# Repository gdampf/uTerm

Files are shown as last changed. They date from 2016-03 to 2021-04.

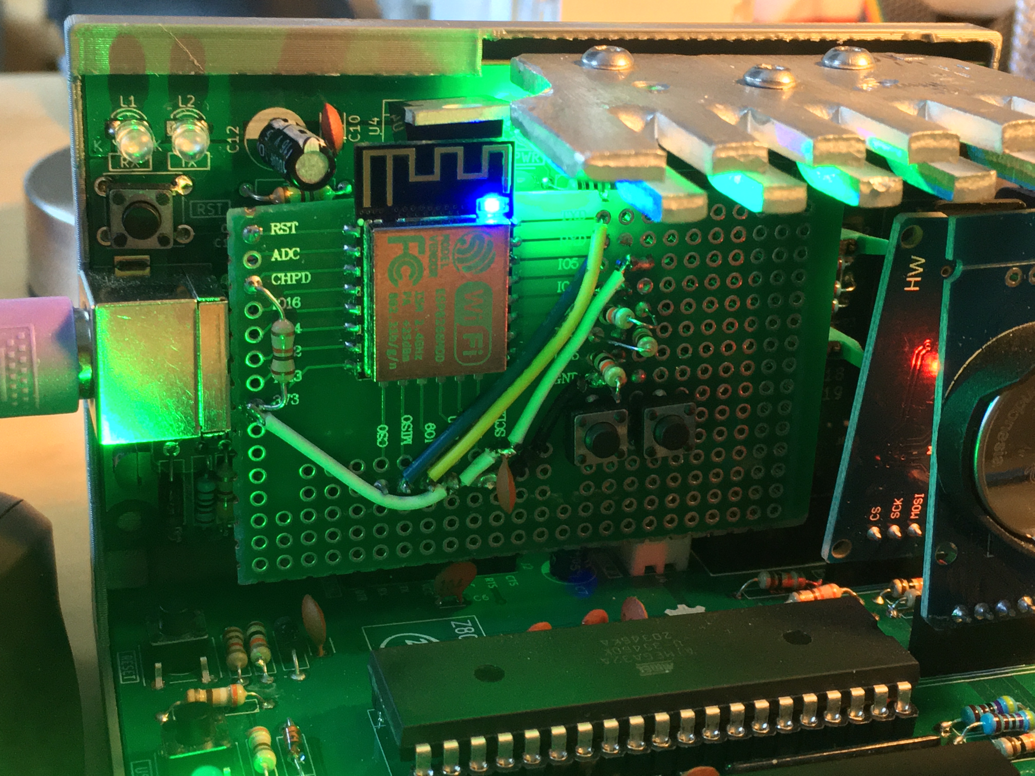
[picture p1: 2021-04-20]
21-04-20 07-18-13 2878.jpg

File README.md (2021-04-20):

## uTerm

uTerm (micro-Term) is a VT100-like terminal for the Z80-MBC2 (https://hackaday.io/project/159973). It has a VGA out and PS/2 keyboard connector, a power supply for the Z80-MBC2 and a "transparent" serial-USB port.

This fork of https://github.com/SuperFabius/uTerm was originally made for supporting German Keyboard-Layout.
Then, I recognized, that some kind of keyboards with PS/2 doesn't react at the given firmware. They are just sending out 0xAA all the time and no key codes. By comparing the signals to a system, where they are working fine, I found that they need a reset (0xff), to work propperly.
This fork solve therefore three things:

1. the state machine for the keyboard has been changed to support this kind of keyboards, which are waiting for reset.
2. the right alt key is now used as a separate modifier to support the ALTGR-Codes on many non US-Keyboard-Layouts.
3. the keys are changed corresponding to German Layout

To compile this code, I used Keil µVision5 under Windows X!

I further added the code for using an ESP8266 for using telnet via WiFi.

Here comes the original Text:

These are the sources modified for the uTerm forked from the Madis Kaal 
repository (forked from the original repository of K. C. Lee: 
https://github.com/FPGA-Computer/STM32F030F4-VGA. Original project 
page: https://hw-by-design.blogspot.com/2018/07/low-cost-vga-terminal-module-project.html)

uTerm "project" page: https://hackaday.io/project/165325

NOTE: I've updated here only the changed source files, so you must recompile all to get the new executable.

Supported uTerm boards:

- A071218-R250119
- A071218-R290319

Supported uTerm-S boards:

- A200419

------------------------------------------------------------------------------

**UPDATE (11/2019):** Solved a bug (by gkaufman) using the right CTRL key in some situations (i.e. CTRL-L)

------------------------------------------------------------------------------

In the following the original text. 

------------------------------------------------------------------------------
------------------------------------------------------------------------------

VT100 emulation, font editor, 16-line font, and support for inverse fonts
added by Madis Kaal <mast@nomad.ee> http://www.nomad.ee

The individual license(s) are in each directories.

Directories:
------------------------------------------------------------------------------
font conv/ 
- source code + Windows console executable for a font conversion program.
It imports GLCD font Creator file and converter it to a C font table
of the comverted scan line bitmaps that is to be used with the VGA library.

- The converter is compiled using Pelles C
http://www.pellesc.de/index.php?page=start&lang=en

- "GLCD Font Creator" MikroElektronika
http://www.mikroe.com/glcd-font-creator/

Code in this directory is licensed under "Simplified BSD License"

-------------------------------------------------------------------------------
STM32F030F4/Hardware/LT Spice Simulation
files in this directory is licensed under "Simplified BSD License"

-------------------------------------------------------------------------------
STM32F030F4/Hardware/Sketchup 3D Model
Creative Commons 4.0 Attribution-NonCommercial-NoDerivs International
http://creativecommons.org/licenses/by-nc-nd/4.0/

This is to prevent someone photoshopping this as their own project for crowd-funding 
scams. You are free to generate your own model using Eagleup from your new layout.

-------------------------------------------------------------------------------
STM32F030F4/Hardware/
Schematic/Layout is distributed with Creative Commons 4.0 Attribution-NonCommercial
http://creativecommons.org/licenses/by-nc/4.0/

If you want to sell this and want a different licensing term, please contact me.

-------------------------------------------------------------------------------
STM32F030F4/Firmware/

Source code distributed under GPLV3, with exception of fontedit.py that is
distributed under BSD license.

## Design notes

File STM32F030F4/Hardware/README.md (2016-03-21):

ChibiTerm
---------
This is the repository for the Low Cost VGA Terminal Module PCB.

Licensing:
Schematic/Layout is distributed with Creative Commons 4.0 Attribution-NonCommercial

3D modelling: Creative Commons 4.0 Attribution-NonCommercial-NoDerivs International
This is to prevent someone photoshopping this as their own project for crowd-funding scams. You are allowed to generate your own model using Eagleup from your new layout.

Creative Commons 4.0 Attribution-NonCommercial:
See http://creativecommons.org/licenses/by-nc/4.0/

Creative Commons 4.0 Attribution-NonCommercial-NoDerivatives International
See http://creativecommons.org/licenses/by-nc-nd/4.0/

If you want to sell this and want a different licensing term, please contact me.

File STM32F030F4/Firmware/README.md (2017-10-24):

This is a STM32F030F4 VGA library + project for HaD 2016 Contest Entry.

Project webpage: 
https://hackaday.io/project/9992

-------------------------------------------------------------------------------
STM32F030F4/Firmware/

Source code distributed under GPLV3 except the font file and startup_stm32f030.s

startup_stm32f030.s:
http://www.st.com/software_license_agreement_liberty_v2

fontedit.py by Madis Kaal is distributed with BSD license
See http://www.nomad.ee

VGA font "Less Perfect DOS VGA" is converted from:
http://laemeur.sdf.org/fonts/
"More Perfect DOS VGA and Less Perfect DOS VGA are both free for all use, 
commercial and non-commercial. IBM designed the glyphs and Zeh Fernando did 
most of the work converting them to TrueType, so I don't claim ownership of 
anything."

VGA font "Term_hex.fon" is converted from:
https://sourceforge.net/projects/realterm/files/z_Special%20Fonts/Hex%20Fonts/
It has a BSD license.

Matrix Clock Demo:
This is a Matrix style Clock running in VGA 640x480 Text mode 
using the schematic in the hardware section.

Source code is a bit rough and out of date with the development branch as this 
is a quick demo for the VGA Text code in its early stage.

ChibiTerm:
This is the source code directory for ChibiTerm terminal program.  This is the
main development branch.

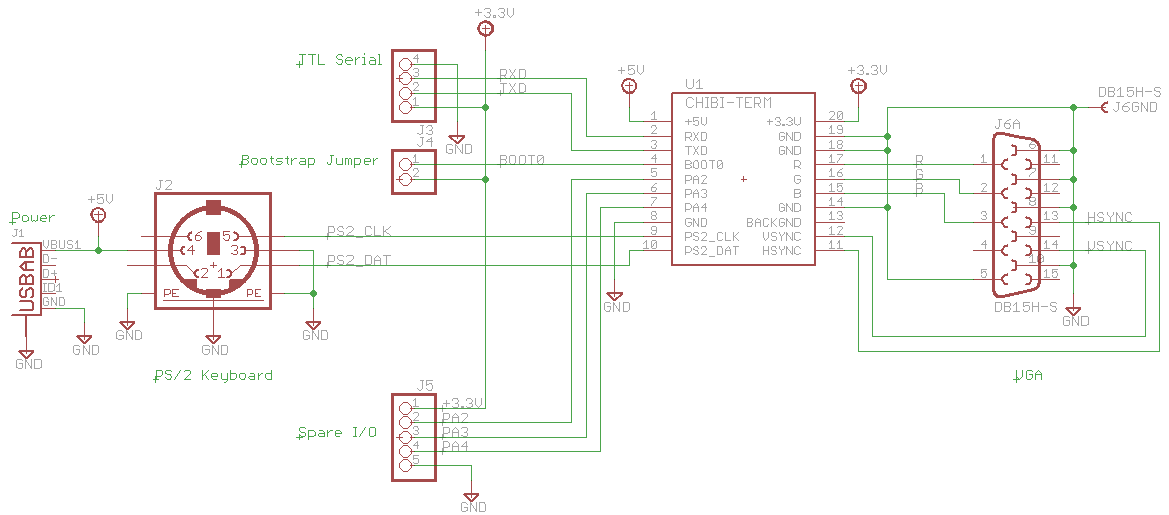
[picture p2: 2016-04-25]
STM32F030F4/Hardware/Module Connections.png

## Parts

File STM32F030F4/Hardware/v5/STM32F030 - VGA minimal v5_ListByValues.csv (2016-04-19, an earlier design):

Qty | Value | Part Num | Package | Parts
1 |  | 0.1 IN HEADER 1X4 | 1X04 | J2
2 |  | 0.1 IN HEADER 1X10 | 1X10 | J1, J3
2 | 0.1uF | 0.1UF, 0603 | CAPC1608X92N | C4, C8
1 | 1uF | 1UF, 0603 | CAPC1608X92N | C9
1 | 1uF | 1UF, 0805 | CAPC2012X145AN | C3
1 | 2K | 2K, 0603 | RESC1608X55N | R4
3 | 4K7 | 4K7, 0603 | RESC1608X55N | R1, R3, R5
2 | 5V1 Zener | BZT52C5V1 | SOD-123 | D1, D2
1 | 10uF | 10UF/10V X5R 0805 | CAPC2012X145AN | C1
3 | 22pF | 22PF, 0603 | CAPC1608X92N | C5, C6, C10
1 | 25MHz | 25MHZ FUND. HC49 | SM49 | X1
2 | 220R | CAT16-221J4 | CAT16 | RN1, RN2
3 | 475R | 475R, 0603 | RESC1608X55N | R2, R6, R7
1 | 3904 | MMBT3904 | SOT95P280X135-3N | Q1
1 | BAT54 | BAT54 | SOT95P280X135-3N | D3
1 | CC-BY-NC | LICENSE | CC-BY-NC-75 | LICENSE
1 | MCP1700/TT | MCP1700T-3302E/TT | SOT95P280X135-3N | U1
1 | STM32F030F4P6 | STM32F030F4P6 | TSSOP20 | U2

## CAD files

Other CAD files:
win32/output/fontconv.obj
STM32F030F4/Hardware/Sketchup 3D Model/Rev. 5.skp

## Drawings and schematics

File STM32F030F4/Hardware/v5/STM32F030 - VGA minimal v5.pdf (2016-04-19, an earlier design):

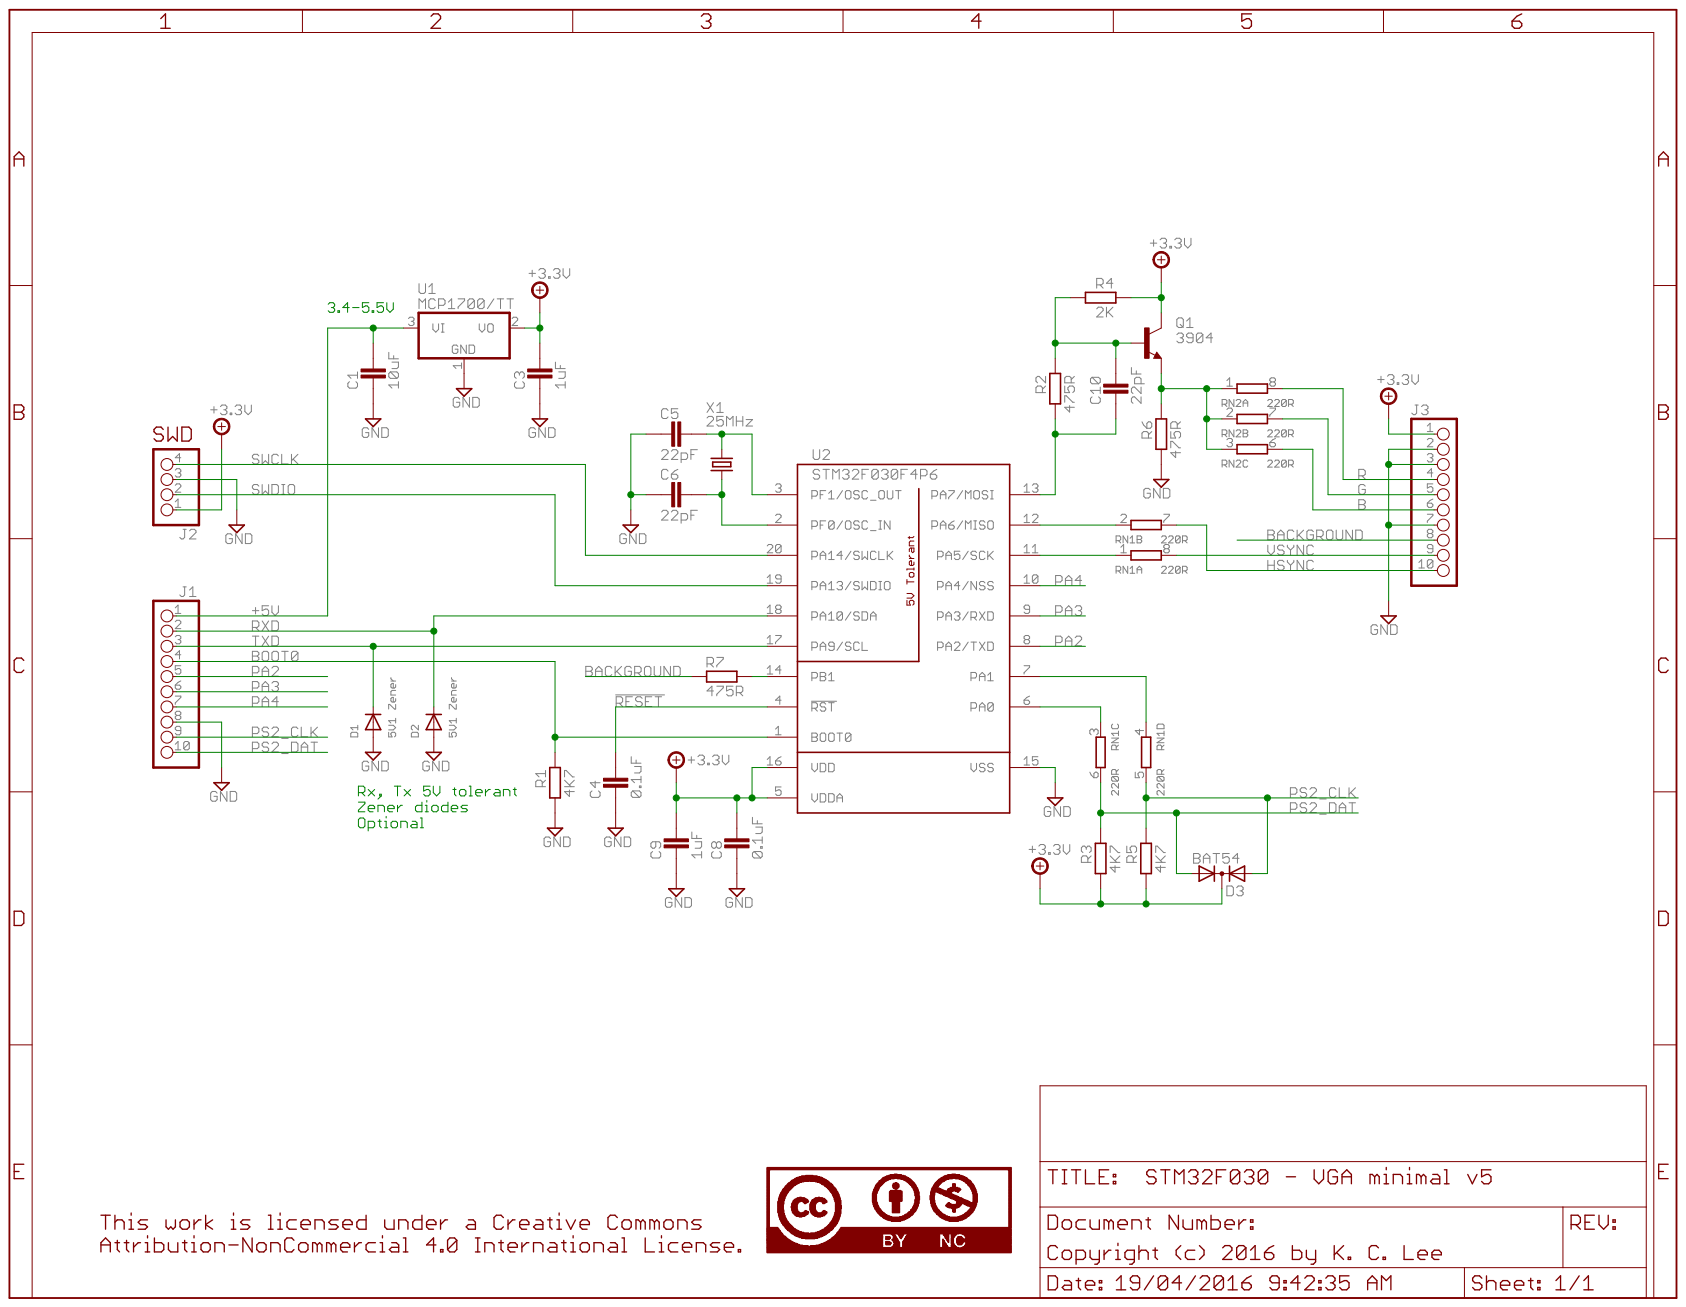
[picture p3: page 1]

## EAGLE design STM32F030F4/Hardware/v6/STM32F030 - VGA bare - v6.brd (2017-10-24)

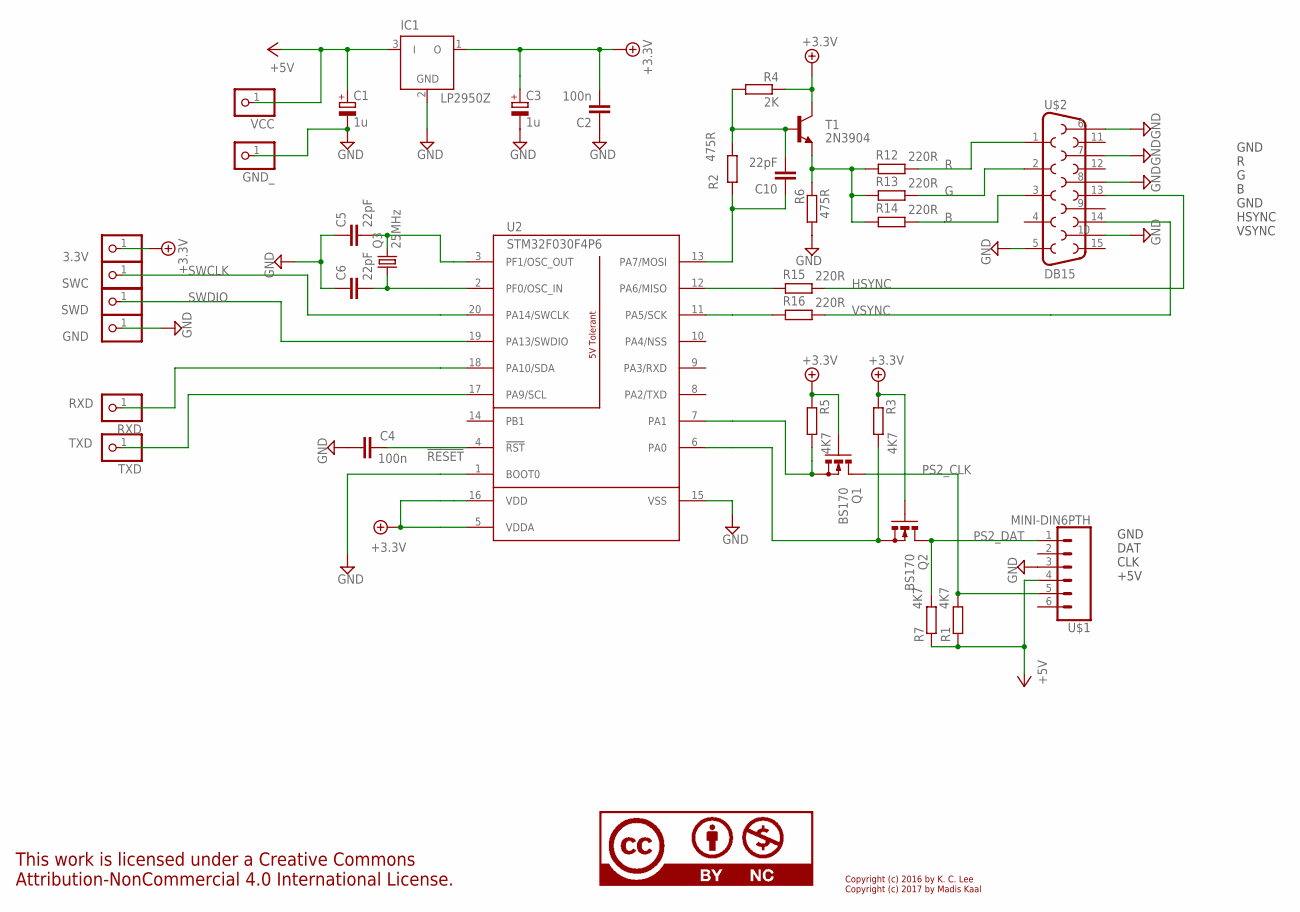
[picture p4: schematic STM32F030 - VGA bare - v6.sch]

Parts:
3.3V: PINHD-1X1; 1X01
C1, C3: 1u; E2,5-5
C2, C4: 100n; C025-025X050; PARTNO 0.1UF, 0603
C5, C6, C10: 22pF; C025-025X050; PARTNO 22PF, 0603
GND: PINHD-1X1; 1X01
GND_: PINHD-1X1; 1X01
IC1: LP2950Z; TO92
LICENSE: CC-BY-NC; CC-BY-NC-75; PARTNO LICENSE
Q1, Q2: BS170; SOT54E
Q3: 25MHz; HC49U-V
R1, R3, R5, R7: 4K7; 0204/7; PARTNO 4K7, 0603
R2, R6: 475R; 0204/7; PARTNO 475R, 0603
R4: 2K; 0204/7; PARTNO 2K, 0603
R12, R13, R14, R15, R16: 220R; 0204/7
RXD: PINHD-1X1; 1X01
SWC: PINHD-1X1; 1X01
SWD: PINHD-1X1; 1X01
T1: 2N3904; TO92
TXD: PINHD-1X1; 1X01
U2: STM32F030F4P6; TSSOP20; PARTNO STM32F030F4P6
U$1: MINI-DIN6PTH; MINI-DIN6
U$2: DB15
VCC: PINHD-1X1; 1X01

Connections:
!RESET: C4.1, U2.4 (!RST)
+3.3V: 3.3V.1, C2.2, C3.+, IC1.1 (O), Q1.G, Q2.G, R3.2, R4.1, R5.2, T1.1 (C), U2.5 (VDDA), U2.16 (VDD)
+5V: C1.+, IC1.3 (I), R1.2, R7.2, U$1.4, VCC.1
B: R14.1, U$2.3
G: R13.1, U$2.2
GND: C1.-, C2.1, C3.-, C4.2, C5.1, C6.1, GND.1, GND_.1, IC1.2 (GND), R6.2, U2.1 (BOOT0), U2.15 (VSS), U$1.3, U$2.5, U$2.6, U$2.7, U$2.8, U$2.10
HSYNC: R15.1, U$2.13
unnamed: R6.1, R12.2, R13.2, R14.2, T1.3 (E)
unnamed: R15.2, U2.12 (PA6/MISO)
unnamed: Q1.S, R5.1, U2.7 (PA1)
unnamed: C5.2, Q3.2, U2.3 (PF1/OSC_OUT)
unnamed: C6.2, Q3.1, U2.2 (PF0/OSC_IN)
unnamed: Q2.S, R3.1, U2.6 (PA0)
unnamed: R16.2, U2.11 (PA5/SCK)
unnamed: C10.2, R2.1, R4.2, T1.2 (B)
unnamed: C10.1, R2.2, U2.13 (PA7/MOSI)
PS2_CLK: Q1.D, R1.1, U$1.5
PS2_DAT: Q2.D, R7.1, U$1.1
R: R12.1, U$2.1
RXD: RXD.1, U2.18 (PA10/SDA)
SWCLK: SWC.1, U2.20 (PA14/SWCLK)
SWDIO: SWD.1, U2.19 (PA13/SWDIO)
TXD: TXD.1, U2.17 (PA9/SCL)
VSYNC: R16.1, U$2.14

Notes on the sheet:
GND R G B GND HSYNC VSYNC
GND DAT CLK +5V
Copyright (c) 2016 by K. C. Lee Copyright (c) 2017 by Madis Kaal

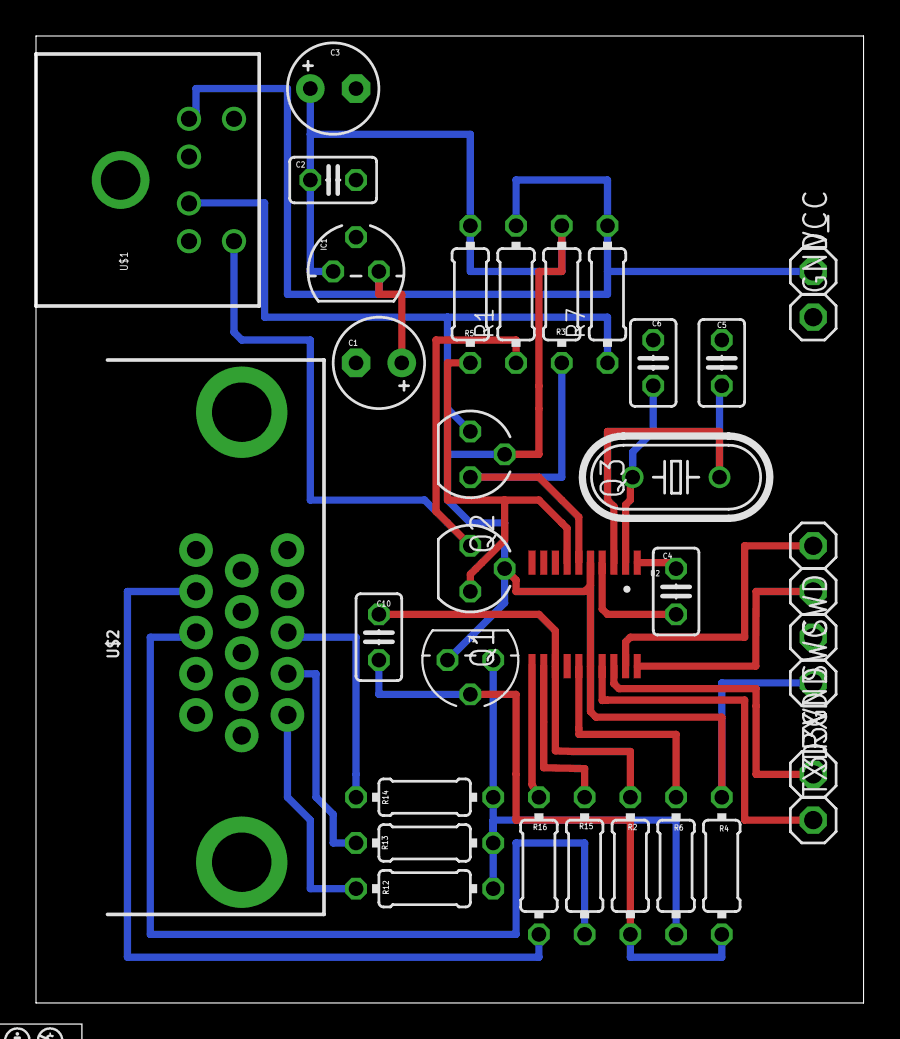
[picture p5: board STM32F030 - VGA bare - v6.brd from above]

Board: 2 copper layers, 46.0 x 53.7 mm, 36 parts (0 on the bottom side), 24 nets.

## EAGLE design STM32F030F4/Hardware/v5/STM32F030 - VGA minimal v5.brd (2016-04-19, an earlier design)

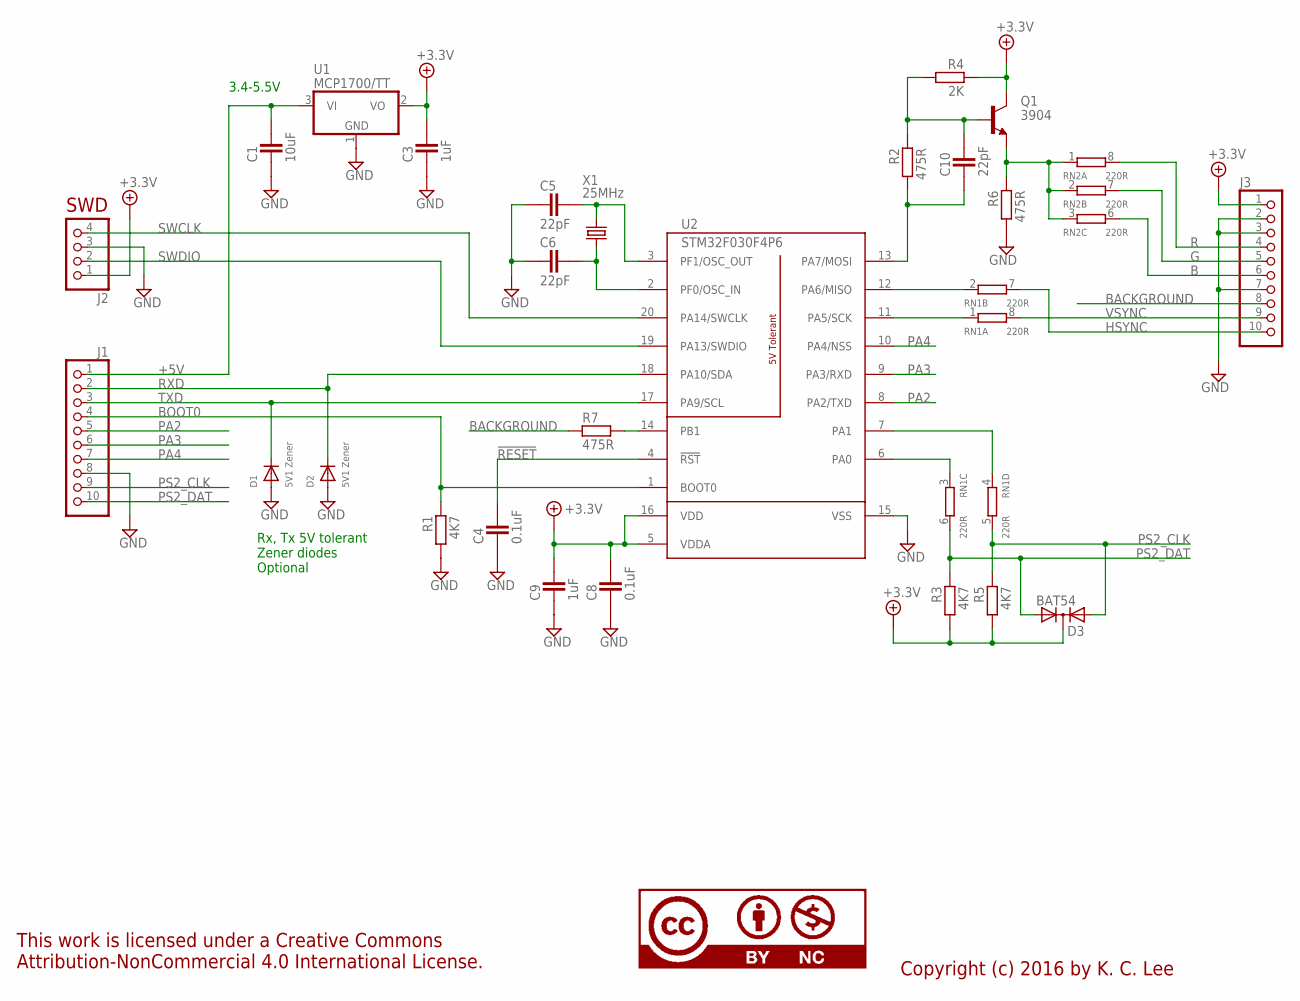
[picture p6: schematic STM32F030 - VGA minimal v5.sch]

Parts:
C1: 10uF; CAPC2012X145AN; PARTNO 10UF/10V X5R 0805
C3: 1uF; CAPC2012X145AN; PARTNO 1UF, 0805
C4, C8: 0.1uF; CAPC1608X92N; PARTNO 0.1UF, 0603
C5, C6, C10: 22pF; CAPC1608X92N; PARTNO 22PF, 0603
C9: 1uF; CAPC1608X92N; PARTNO 1UF, 0603
D1, D2: 5V1 Zener; SOD-123; PARTNO BZT52C5V1
D3: BAT54; SOT95P280X135-3N; PARTNO BAT54
J1, J3: PINHD-1X10; 1X10; PARTNO 0.1 IN HEADER 1X10
J2: PINHD-1X4_2.54; 1X04; PARTNO 0.1 IN HEADER 1X4
LICENSE: CC-BY-NC; CC-BY-NC-75; PARTNO LICENSE
Q1: 3904; SOT95P280X135-3N; PARTNO MMBT3904
R1, R3, R5: 4K7; RESC1608X55N; PARTNO 4K7, 0603
R2, R6, R7: 475R; RESC1608X55N; PARTNO 475R, 0603
R4: 2K; RESC1608X55N; PARTNO 2K, 0603
RN1, RN2: 220R; CAT16; PARTNO CAT16-221J4
U1: MCP1700/TT; SOT95P280X135-3N; PARTNO MCP1700T-3302E/TT
U2: STM32F030F4P6; TSSOP20; PARTNO STM32F030F4P6
X1: 25MHz; SM49; PARTNO 25MHZ FUND. HC49

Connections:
!RESET: C4.2, U2.4 (!RST)
+3.3V: C3.2, C8.2, C9.2, D3.3 (K), J2.1, J3.1, Q1.3 (C), R3.2, R4.1, R5.2, U1.2 (VO), U2.5 (VDDA), U2.16 (VDD)
+5V: C1.2, J1.1, U1.3 (VI)
B: J3.6, RN2.6 (2)
BACKGROUND: J3.8, R7.1
BOOT0: J1.4, R1.1, U2.1 (BOOT0)
G: J3.5, RN2.7 (2)
GND: C1.1, C3.1, C4.1, C5.1, C6.1, C8.1, C9.1, D1.A, D2.A, J1.8, J2.3, J3.2, J3.3, J3.7, R1.2, R6.2, U1.1 (GND), U2.15 (VSS)
HSYNC: J3.10, RN1.7 (2)
unnamed: Q1.2 (E), R6.1, RN2.1, RN2.2 (1), RN2.3 (1)
unnamed: RN1.2 (1), U2.12 (PA6/MISO)
unnamed: RN1.4 (1), U2.7 (PA1)
unnamed: R7.2, U2.14 (PB1)
unnamed: C5.2, U2.3 (PF1/OSC_OUT), X1.2
unnamed: C6.2, U2.2 (PF0/OSC_IN), X1.1
unnamed: RN1.1, U2.11 (PA5/SCK)
unnamed: RN1.3 (1), U2.6 (PA0)
unnamed: C10.2, Q1.1 (B), R2.1, R4.2
unnamed: C10.1, R2.2, U2.13 (PA7/MOSI)
PA2: J1.5, U2.8 (PA2/TXD)
PA3: J1.6, U2.9 (PA3/RXD)
PA4: J1.7, U2.10 (PA4/NSS)
PS2_CLK: D3.2 (A2), J1.9, R5.1, RN1.5 (2)
PS2_DAT: D3.1 (A1), J1.10, R3.1, RN1.6 (2)
R: J3.4, RN2.8 (2)
RXD: D2.C, J1.2, U2.18 (PA10/SDA)
SWCLK: J2.4, U2.20 (PA14/SWCLK)
SWDIO: J2.2, U2.19 (PA13/SWDIO)
TXD: D1.C, J1.3, U2.17 (PA9/SCL)
VSYNC: J3.9, RN1.8 (2)

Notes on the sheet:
3.4-5.5V
Rx, Tx 5V tolerant Zener diodes Optional
Copyright (c) 2016 by K. C. Lee
SWD

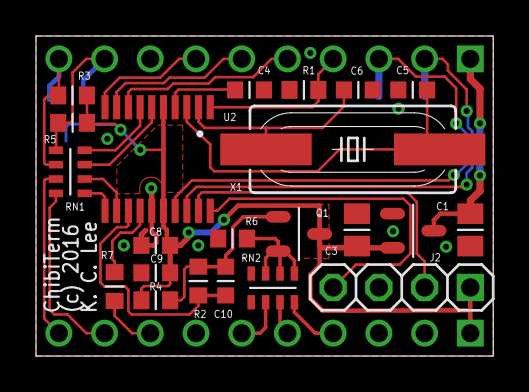
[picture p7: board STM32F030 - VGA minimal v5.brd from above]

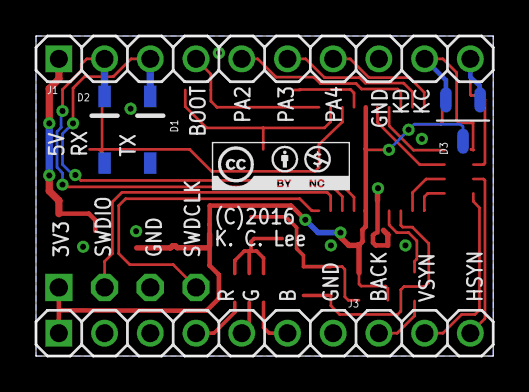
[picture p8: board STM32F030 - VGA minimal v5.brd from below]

Board: 2 copper layers, 25.4 x 17.8 mm, 28 parts (6 on the bottom side), 30 nets.

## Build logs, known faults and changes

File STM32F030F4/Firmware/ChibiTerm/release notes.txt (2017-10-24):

This is for Keil MDK.

Ver. 0.0 - Initial Release - 18th Apr 2016
I have cleaned up the code a bit and squeeze the code for RAM (40 bytes free).
It is stable enough to be used as a dumb terminal, but incomplete as the ANSI 
escape code handling and keyboard handling are not yet finished.

Ver. 1.0 - VT100 emulation - 24th Oct 2017 by Madis Kaal <mast@nomad.ee> 
  http://www.nomad.ee

* added full 256 character bitmap font where upper half is in inverse, so
  that line drawing characters and inverse text are available via standard
  VT100 escape sequences
* added VT100 line drawing characters and some extras into low 32 bytes of
  character set
* switched to 16 scan line character set, reducing number of text lines to
  30. this freed up memory needed for VT100 and increased serial FIFO-s
* added VT100 emulation, works well with joe/nano/top/midnight commander
  when attached as serial console to OSX machine. Also works fine with
  everything except midnight commander when I ssh to linux machine. mc
  on does not seem to know how to draw VT100 line characters.
* also emulating VT100 keyboard to reasonable extent. Cursor keys, function
  keys etc. seem to work with editors/midnight commander on OSX. Only US
  layout currently mapped, as character sets are only US-ASCII anyway.
* added quick and dirty font editor (fontedit.py) for tweaking the font
  files
* Added v6 schematics and rough PCB layout with mostly through-hole parts
  under hardware section, showing all parts required to build hardware as
  complete unit with connectors. The only real change is added level
  shifters for keyboard interface instead of dodgy clamping diodes on clock
  and data lines.
* added .hex file into repository so that you dont have to install Keil
  tools if you just want to build it.

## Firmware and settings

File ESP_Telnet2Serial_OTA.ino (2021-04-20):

/*--------------------------------------------------
Telnet to Serial AccessPoint for ESP8266 
for ESP8266 adapted Arduino IDE

by Stefan Thesen 08/2015 - free for anyone
http://blog.thesen.eu

Creates an accesspoint or network client which can 
be connected by telnet; e.g. telnet 192.168.4.1
Telnet input is sent to serial and vice versa.

Serial output can e.g. be used to steer an attached
Arduino or other serial interfaces.
Please take care for levels of the serial lines.

Code inspired by a post of ghost on github:
https://github.com/esp8266/Arduino/issues/307
--------------------------------------------------*/
#include <HardwareSerial.h>
#include <ESP8266WiFi.h>
#include <ESP8266mDNS.h>
#include <WiFiUdp.h>
#include <ArduinoOTA.h>

#define BUFFERSIZE 512

////////////////////////////////////
// settings for Telnet2Serial Bridge
////////////////////////////////////

// max number of clients that can connect
#define MAX_NO_CLIENTS 5

//#define AP_MODE

// shall local echo in telnet be suppressed (usually yes)
#define SUPPRESSLOCALECHO 

// speed of the serial connection
#define SERIALSPEED 115200

#ifdef AP_MODE
  const WiFiMode wifi_mode = WIFI_AP;     // access-point
  const char* ssid = "TEL2SER";   // Name of AP 
#else
  const WiFiMode wifi_mode = WIFI_STA;     // WIFI client
  const char* ssid = "XXXXX";   // Name of Wifi to connect to (for WIFI_STA)
#endif
const char* password = "XXXXX";      // set to "" for open access point w/o password

// Create an instance of the server on Port 23
WiFiServer server(23);
WiFiClient pClientList[MAX_NO_CLIENTS]; 
char sbuf[BUFFERSIZE];

void setup() 
{
  // start serial
  Serial.setRxBufferSize(BUFFERSIZE);
  Serial.begin(SERIALSPEED);

  pinMode(LED_BUILTIN,OUTPUT);

  WiFi.mode(wifi_mode);
  #ifdef AP_MODE
    WiFi.softAP(ssid, password);
  #else
    // network cient - inital connect
    WiFiStart();
  #endif

  // Port defaults to 8266
  ArduinoOTA.setPort(8266);

  // Hostname defaults to esp8266-[ChipID]
  ArduinoOTA.setHostname("TEL2SER");

  // No authentication by default
  ArduinoOTA.setPassword("XXXXX");

  // Password can be set with it's md5 value as well
  // MD5(admin) = 21232f297a57a5a743894a0e4a801fc3
  // ArduinoOTA.setPasswordHash("21232f297a57a5a743894a0e4a801fc3");

  ArduinoOTA.onStart([]() {
    Serial.println("#Start updating sketch");
  });
  ArduinoOTA.onEnd([]() {
    Serial.println("\n#End");
  });
  ArduinoOTA.onProgress([](unsigned int progress, unsigned int total) {
    Serial.printf("Progress: %u%%\r", (progress / (total / 100)));
  });
  ArduinoOTA.onError([](ota_error_t error) {
    Serial.printf("#Error[%u]: ", error);
    if (error == OTA_AUTH_ERROR) {
      Serial.println("Auth Failed");
    } else if (error == OTA_BEGIN_ERROR) {
      Serial.println("Begin Failed");
    } else if (error == OTA_CONNECT_ERROR) {
      Serial.println("Connect Failed");
    } else if (error == OTA_RECEIVE_ERROR) {
      Serial.println("Receive Failed");
    } else if (error == OTA_END_ERROR) {
      Serial.println("End Failed");
    }
  });
  ArduinoOTA.begin();

  #ifndef AP_MODE
    IPAddress ip = WiFi.localIP();
    Serial.println();
    Serial.print("Connected : ");
    Serial.println(ip);
  #endif
  // Start the server
  server.begin();
  server.setNoDelay(true);
}

#ifndef AP_MODE
  void WiFiStart()
  { 
    // Connect to WiFi network
    WiFi.begin(ssid, password);
  
    if (WiFi.waitForConnectResult() != WL_CONNECTED) ESP.restart();
  }
#endif

void delay_OTA(unsigned long msec)
{
  if (msec == 0)
  {
    ArduinoOTA.handle();
    yield();    
    return;
  }

  unsigned long stopm = millis() + msec;
  while (stopm > millis())
  {
    ArduinoOTA.handle();
    yield();    
  }
}

void loop() 
{ 
  int ii;

  ////////////////////////////////////////////////
  // if network client: check if WLAN is connected
  ////////////////////////////////////////////////
  #ifndef AP_MODE
    if (WiFi.status() != WL_CONNECTED)
    {
      WiFiStart();
      // Start the server
      server.begin();
      server.setNoDelay(true);
    }
  #endif
  
  /////////////////////
  // handle new clients
  /////////////////////
  if (server.hasClient())
  {
    bool bFoundPlace=false;
    
    // search a free spot
    for(ii = 0; ii < MAX_NO_CLIENTS; ii++)
    {
      if (!pClientList[ii] || !pClientList[ii].connected())
      {
        // remove old connections
        if(pClientList[ii]) 
        {
          pClientList[ii].stop();
        }

        // new client
        pClientList[ii] = server.available();
	      #ifdef SUPPRESSLOCALECHO
          pClientList[ii].write("\xFF\xFB\x01", 3); 
        #endif
        pClientList[ii].write("Welcome to Telnet2Serial Adapter - S. Thesen 08/2015 - https://blog.thesen.eu\r\n"); 
        bFoundPlace=true;
        break;
      }
    }

    //no free spot --> sorry
    if (!bFoundPlace)
    {
      WiFiClient client = server.available();
      client.stop();
    }
  }

  /////////////////////
  // Telnet --> Serial
  /////////////////////
  for(ii = 0; ii < MAX_NO_CLIENTS; ii++)
  {
    if (pClientList[ii] && pClientList[ii].connected())
    {
      if(pClientList[ii].available())
      {
        while(pClientList[ii].available()) 
        {
          char c = pClientList[ii].read();
          if ((c > 0) && (c <= 127)) Serial.write(c);
          delay_OTA(1);
        }
      }
    }
  }

  /////////////////////
  // Serial --> Telnet
  /////////////////////
  if(Serial.available())
  {
    size_t len = Serial.read(sbuf, BUFFERSIZE);
    ArduinoOTA.handle();

    for(ii = 0; ii < MAX_NO_CLIENTS; ii++)
    {
      if (pClientList[ii] && pClientList[ii].connected())
      {
        pClientList[ii].write(sbuf, len);
        delay_OTA(1);
      }
    }
  }
  ArduinoOTA.handle();
}

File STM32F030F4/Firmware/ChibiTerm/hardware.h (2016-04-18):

/*
 * hardware.h
 *
 * Created: March-14-16, 4:52:17 PM
 *  Author: K. C. Lee
 * Copyright (c) 2016 by K. C. Lee 
 
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
	If not, see http://www.gnu.org/licenses/gpl-3.0.en.html
 */ 

#ifndef _HARDWARE_H_
#define _HARDWARE_H_

#include "gpio.h"

#define GPIOA_MODER (PIN_ALT(PA14)|PIN_ALT(PA13)|				/* SWCLK, SWDIO */	\
										 PIN_ALT(PA10)|PIN_ALT(PA9)|				/* RxD, TxD			*/	\
										 PIN_OUTPUT(PA4)|										/* ??? ???			*/	\
										 PIN_OUTPUT(PA3)|PIN_OUTPUT(PA2)|		/* ??? ???			*/	\
		                 PIN_OUTPUT(PA1)|PIN_OUTPUT(PA0))		/* PS/2 PS/2		*/	\

#define GPIOA_PUPDR	 (PIN_PULLUP(PA10))
#define GPIOA_OTYPER (PIN_OPENDRAIN(PA1)|PIN_OPENDRAIN(PA0))	// PS/2
#define GPIOA_BSRR	 (PIN_SET(PA1)|PIN_SET(PA0))
#define GPIOA_AFR1	 (PIN_AFRH(PA14,0)|PIN_AFRH(PA13,0)|/* SWCLK, SWDIO	*/	\
											PIN_AFRH(PA10,1)|PIN_AFRH(PA9,1))	/* RxD, TxD 		*/


#endif

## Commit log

2016-03-16 added options for font conv
    [fontconv.obj]
2016-03-21 PCB Rev 1 release
    [Rev. 4.skp, STM32F030 - VGA minimal v4.brd, STM32F030 - VGA minimal v4.sch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]
2016-03-21 PCB Rev 1 add BOM
    [STM32F030 - VGA minimal v4_ListByValues.csv]
2016-03-21 PCB Rev 1 - fix BOM
    [STM32F030 - VGA minimal v4_ListByValues.csv]
2016-03-21 PCB Rev 1 - fix BOM take 2
    [STM32F030 - VGA minimal v4_ListByValues.csv]
2016-03-21 PCB Rev 1 - fix BOM take 3
    [STM32F030 - VGA minimal v4_ListByValues.csv]
2016-03-21 PCB Rev 1 - fix BOM take 4
    [STM32F030 - VGA minimal v4_ListByValues.csv]
2016-03-21 PCB Rev 1 - fix BOM take 5
    [STM32F030 - VGA minimal v4_ListByValues.csv]
2016-03-21 PCB Rev 1 - fix BOM take 6
    [STM32F030 - VGA minimal v4_ListByValues.csv]
2016-04-18 ChibiTerm source snapshot
    [STM32F030 - VGA minimal v4.brd, STM32F030 - VGA minimal v4.sch, STM32F030 - VGA minimal v4_ListByValues.csv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]
2016-04-18 ChibiTerm source snapshot take 3
    [STM32F030 - VGA minimal v5.brd, STM32F030 - VGA minimal v5.sch, STM32F030 - VGA minimal v5_ListByValues.csv]
2016-04-18 ChibiTerm source snapshot take 4
    [STM32F030 - VGA minimal v5.brd, STM32F030 - VGA minimal v5.sch, STM32F030 - VGA minimal v5_ListByValues.csv]
2016-04-18 V5 Schematic/layout/3D model
    [Rev. 4.skp, Rev. 5.skp, STM32F030 - VGA minimal v5.brd]
2016-04-19 Zener diodes value change
    [STM32F030 - VGA minimal v5.brd, STM32F030 - VGA minimal v5.sch, STM32F030 - VGA minimal v5_ListByValues.csv]
2016-04-25 VGA pin 9 is a RES/PWR. :(
2017-10-24 VT100 emulation added
    [STM32F030 - VGA bare - v6.brd, STM32F030 - VGA bare - v6.sch]
2021-04-20 Delete STM32F030F4/Firmware/ChibiTerm/Listings directory
    Deleting Listings (no value)
2021-04-20 modified sketch for arduino
    This sketch is modified to allow OTA updates, but originally based on the code found here: http://blog.thesen.eu
    See picture for usage. The wiring is just trivial, as you just have to connect TxD, RxD, Vcc, Gnd and some protecting resistors.
    Buttons are for reset and wired programming only.
    [ESP_Telnet2Serial_OTA.ino]

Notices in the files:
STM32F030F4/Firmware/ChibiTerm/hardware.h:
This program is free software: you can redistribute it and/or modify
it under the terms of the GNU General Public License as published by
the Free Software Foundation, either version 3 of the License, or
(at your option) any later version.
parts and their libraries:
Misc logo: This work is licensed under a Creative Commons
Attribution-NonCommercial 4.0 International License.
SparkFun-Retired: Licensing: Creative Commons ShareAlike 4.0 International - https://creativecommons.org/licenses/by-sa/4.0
